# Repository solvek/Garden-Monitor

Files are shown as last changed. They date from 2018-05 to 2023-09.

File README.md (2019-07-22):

# Garden Monitor
A useful monitor for garden displaying information on dot-matrix
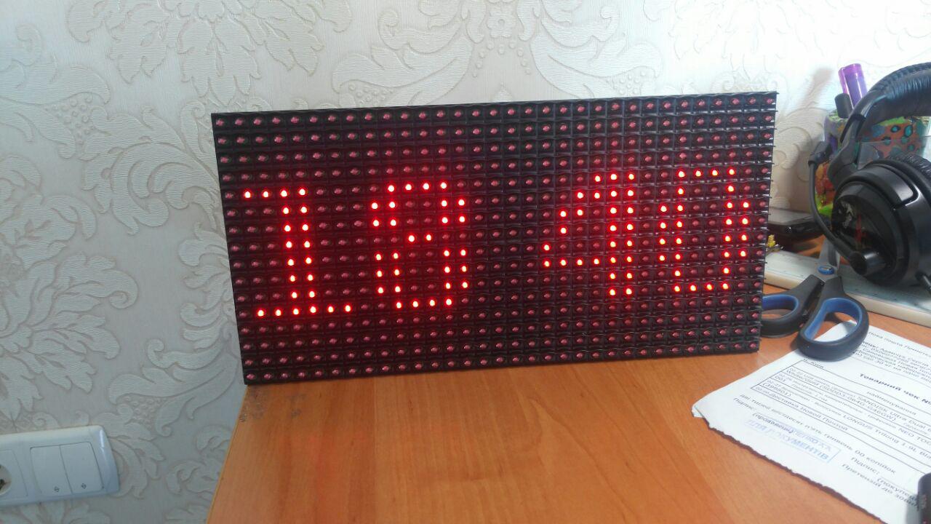
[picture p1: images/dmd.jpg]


# Terminal Commands

|Format|Description|Details|
|--|--|--|
|`#TYYMMDDDwHHmmSS`|Setting time|`#T19052405180500`.  `Dw` - day of week, Monday - `01`, Sunday - `07`|
|`#R`|Resets the device|
|`#BNNN`|Setting brightness|NNN - are 3 digits. Use 015 for 15. The value between 000 and 255|
|`#KSNNN`|Sends current temperature from sensor|NNN - are 3 digits. Use 015 for 15. S - sign "-" or "+"|
|`#CNNNMMM`|Sets temperature correction parameters|NNN and MMM - are bytes B and K. Example `#C128098`|

# Hardware

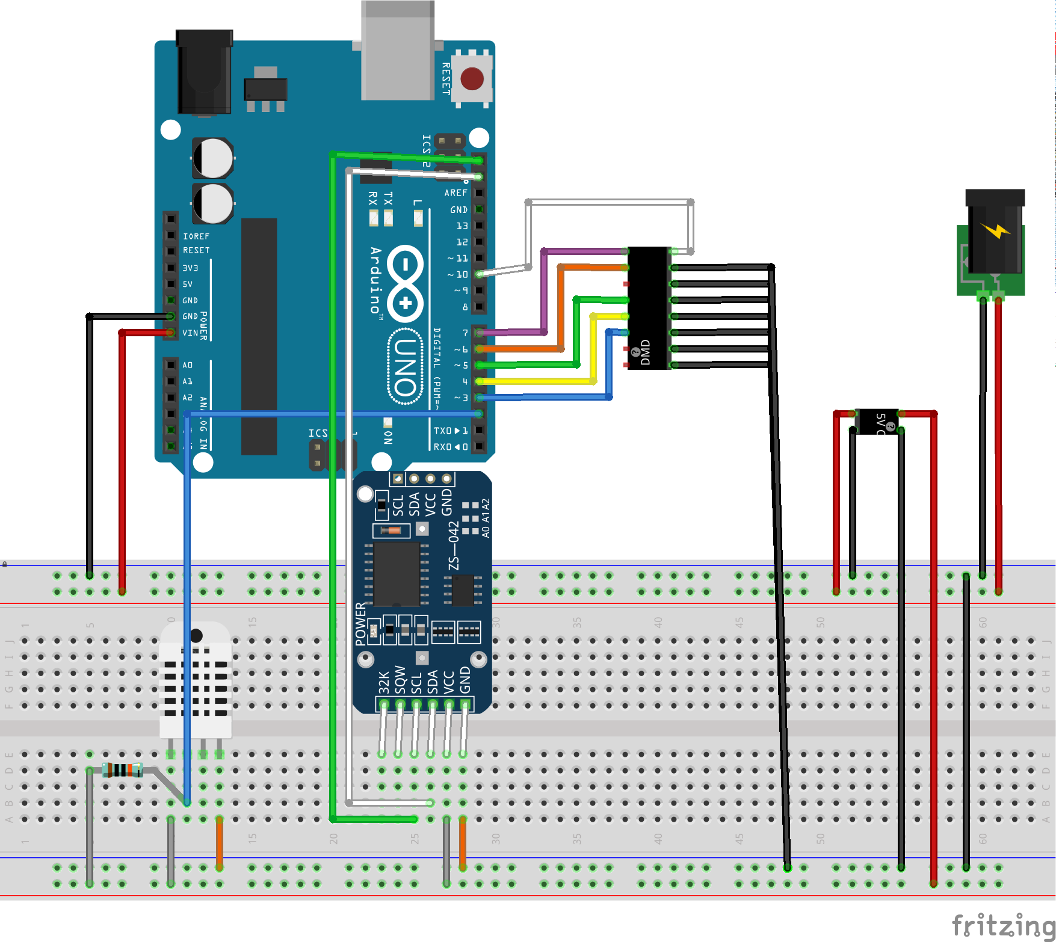
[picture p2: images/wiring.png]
Garden monitor wiring


I played with different controllers. P10 screen works with operating voltage 5V so only Anrduino Uno worked fine.

## [RTC](https://www.makeuseof.com/tag/how-and-why-to-add-a-real-time-clock-to-arduino/)

* [DS3231 Library](https://github.com/NorthernWidget/DS3231

## DHT22
Temperature and humidity sensor
* [DHT Library](https://github.com/adafruit/DHT-sensor-library)

## P10 Dot-Matrix display
 * [DMD2 Library](https://github.com/freetronics/DMD2)
 * [Instructable article](http://www.instructables.com/id/Display-Text-at-P10-LED-Display-Using-Arduino/)
 * [Linking dot matrix to Arduino](https://maker.pro/projects/arduino/arduino-led-matrix-controlled-android-app-greenpaks-i2c)
 *  [Font creator (Java based, use GLCDFontCreator2.zip)](https://code.google.com/archive/p/glcd-arduino/downloads)
	 * Running FontCreator:  `java -classpath . FontCreator`

### Wiring
Because BLE shield and DMD conflict for pins I used not standard DMD pins (`Arduino(Def)`) but custom (`Arduino(My)`)

|Letter|Meaning|Wire|Arduino(Def)|Arduino(My)|ESP8266|D1/R1|
|--|--|--|--|--|--|--|
|OE|NOE|White|D9|D10|GPIO15|D8|
|A|A|Purple|D6|D7|GPIO16|D2|
|B|B|Orange|D7|D6|GPIO12|D6|
|S|sck|Green|D13|D5|GPIO14|D5|
|L|clk|Yellow|D8|D4|GPIO0|D10|
|R|R|Blue|D11|D3|GPIO13|D7|

### Bus mapping

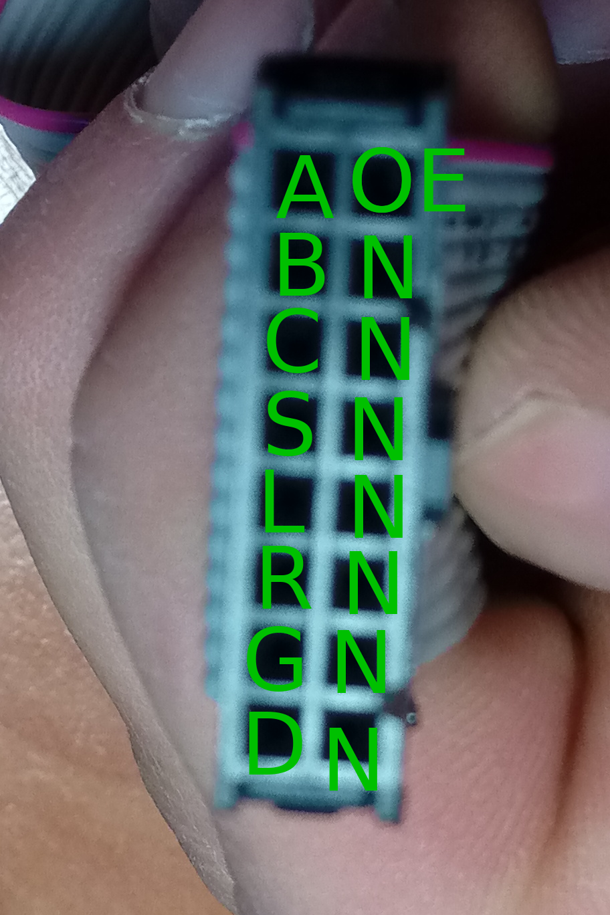
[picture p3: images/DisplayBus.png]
Bus mapping


[Connecting to ESP8266](http://forum.freetronics.com/viewtopic.php?t=6687)

## BLE Shield
 * [Library](https://github.com/RedBearLab/nRF8001)

## Other hardware
### [The 74HC595 Shift Register](https://learn.adafruit.com/adafruit-arduino-lesson-4-eight-leds/the-74hc595-shift-register)

### [Wemos D1/R1 Controller](https://wiki.wemos.cc/products:d1:d1)

 * [Mapping GPIOs to Ds](https://jardikblog.wordpress.com/2016/11/02/wemos-d1-r1-vs-wemos-d1-r2/)
 * [How to Program ESP8266 with Arduino UNO](https://www.hackster.io/harshmangukiya/how-to-program-esp8266-with-arduino-uno-efb05f)

|Arduino|D1/R1 label|GPIO|
|--|--|--|
|D2|TX1/D9|GPIO2|
|D6|D2|GPIO16|
|D7|D12/MISO/D6|GPIO12|
|D8|D10/SS|GPIO15|
|D9|D8|GPIO0|
|D11|D11/MOSI/D7|GPIO13|
|D13|D13/SCK/D5|GPIO14|
|A4|D14/SDA/D4|GPIO4|
|A5|D15/SCL/D3|GPIO5|

#### Libraries
##### [WiFiManager](https://github.com/tzapu/WiFiManager)
##### [NTPClient](https://github.com/arduino-libraries/NTPClient)
##### [ArduinoJson](https://github.com/bblanchon/ArduinoJson)
  
# Accuweather
* [Request for current weather condition](https://developer.accuweather.com/accuweather-current-conditions-api/apis/get/currentconditions/v1/%7BlocationKey%7D)
* Kyiv location key: 324505
# Others
 * [Online Markdown editor](https://stackedit.io)

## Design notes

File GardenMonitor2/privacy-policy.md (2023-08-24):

# Privacy Policy

Garden Monitor takes your privacy seriously. To better protect your privacy I provide this privacy policy notice explaining the way your personal information is collected and used.

## Collection of Routine Information

This app track basic information about their "users". This information includes, but is not limited to, IP addresses, "app" details, timestamps and referring pages. None of this information can personally identify specific "user" to this "app". The information is tracked for routine administration and maintenance purposes.

## Cookies

Where necessary, this "app" uses cookies to store information about a visitor’s preferences and history in order to better serve the "user" and/or present the "user" with customized content.

## Advertisement and Other Third Parties

Advertising partners and other third parties may use cookies, scripts and/or web beacons to track "user" activities on this "app" in order to display advertisements and other useful information. Such tracking is done directly by the third parties through their own servers and is subject to their own privacy policies. This "app" has no access or control over these cookies, scripts and/or web beacons that may be used by third parties. Learn how to [opt out of Google’s cookie usage](http://www.google.com/privacy_ads.html).

## Links to Third Party Websites

"I" have included links on this "app" for your use and reference. "I" are not responsible for the privacy policies on these websites. You should be aware that the privacy policies of these websites may differ from "my" own.

## Security

The security of your personal information is important to "us", but remember that no method of transmission over the Internet, or method of electronic storage, is 100% secure. While "I" strive to use commercially acceptable means to protect your personal information, "I" cannot guarantee its absolute security.

## Changes To This Privacy Policy

This Privacy Policy is effective as of 08/24/2023 and will remain in effect except with respect to any changes in its provisions in the future, which will be in effect immediately after being posted on this page.

"I" reserve the right to update or change "my" Privacy Policy at any time and you should check this Privacy Policy periodically. If "I" make any material changes to this Privacy Policy, "I" will notify you either through the email address you have provided "me", or by placing a prominent notice on "my" "app".

## Contact Information

For any questions or concerns regarding the privacy policy, please send "me" an email to sergi79@ukr.net.

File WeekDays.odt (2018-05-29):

П | ВТ | СР | ЧТ | ПТ | СБ | Н
П | ВТ | СР | ЧТ | ПТ | СБ | Н
П | ВТ | СР | ЧТ | ПТ | СБ | Н

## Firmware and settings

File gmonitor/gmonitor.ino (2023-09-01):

//"RBL_nRF8001.h/spi.h/boards.h" is needed in every new project
#include <SPI.h>
#include <EEPROM.h>
#include <boards.h>
#include <RBL_nRF8001.h>

#include <DMD2.h>
#include "fonts/GMSolvek.h"

#define panel_width 1
#define panel_heigh 1

#ifdef ESP8266
SPIDMD dmd(panel_width, panel_heigh, D3, D4, D6, D10);
#else
#define PIN_NOE 10 // White
#define PIN_A 7 // Purple
#define PIN_B 6 // Orange
#define PIN_SCK 5 // Green, Latch
#define PIN_CLK 4 // Yellow
#define PIN_R 3 // Blue, MOSI
SoftDMD dmd(panel_width,panel_heigh, PIN_NOE, PIN_A, PIN_B, PIN_SCK, PIN_CLK, PIN_R);
#endif

// Number of P10 panels used X, Y
DMD_TextBox box(dmd, 2, 1, 32, 16); 
//// Set Box (dmd, x, y, Height, Width)

#include <DHT.h>
#include <Wire.h>

#define DHTPIN 2     // what pin we're connected to
#define DHTTYPE DHT22   // DHT 22  (AM2302)
DHT dht(DHTPIN, DHTTYPE); //// Initialize DHT sensor for normal 16mhz Arduino

#include "DS3231.h"
RTClib RTC;
DS3231 Clock;

#define ADDR_BRIGHTNESS 116
#define ADDR_T_CORR 120

double correl_b, correl_k;

#include "Config.h"

#define STATE_TIME 1
#define STATE_TICK_ON 2
#define STATE_TICK_OFF 3
#define STATE_TICK_DATE 4
#define STATE_TICK_TEMP 5

byte state = 0;
long state_time;
long m, recentM = -100000;
byte tick;


void setup()
{  
  // Enable serial debug
  Serial.begin(57600);
  
  Serial.println(F("Started device"));

  dmd.setBrightness(EEPROM.read(ADDR_BRIGHTNESS));
  dmd.selectFont(GMSolvek); // Font used
  dmd.begin();     // Start DMD 
  Serial.println(F("Display initialized"));  
  
  // Default pins set to 9 and 8 for REQN and RDYN
  // Set your REQN and RDYN here before ble_begin() if you need
  // ble_set_pins(3, 2);
  
  // Set your BLE Shield name here, max. length 10
  ble_set_name("SolvekGM");
  
  // Init. and start BLE library.
  ble_begin();

  // DHT init
  dht.begin();
  Wire.begin();

  byte paramB = EEPROM.read(ADDR_T_CORR),
    paramD = EEPROM.read(ADDR_T_CORR+1);
  setCorrelation(paramB, paramD);
}

int c;

#define CHANNEL_SERIAL 1
#define CHANNEL_BLE 2
int channel = CHANNEL_SERIAL;

// Buffer for BLE
unsigned char buf[16] = {0};
unsigned char len = 0;

void loop()
{
  m = millis();
  if (m-recentM>state_time) nextState();
  
  if ( ble_available() )
  {
    while ( ble_available() ){
      c = ble_read();
      if (c==35){
        channel = CHANNEL_BLE;
        readCommand();
      }
      
      Serial.write(c);
    }
      
    Serial.println();
  }
  
  if ( Serial.available() )
  {
    delay(5);
    
    while ( Serial.available() ){
      c = Serial.read();
      if (c==35){
        channel = CHANNEL_SERIAL;
        readCommand();
      }
//      Serial.println(c);
      ble_write(c);
    }
  }
  
  ble_do_events();
}

void nextState(){
  recentM = m;
  transitState();
  state_time = 500;
  switch(state){
    case STATE_TIME:
      showTime();
      tick = 0;
      break;
    case STATE_TICK_ON:
      showTickOn();
      break;            
    case STATE_TICK_OFF:
      showTickOff();
      break;      
    case STATE_TICK_DATE:
      state_time = DELAY_DATE*1000;
      showDate();
      break;      
    case STATE_TICK_TEMP:
      state_time = DELAY_TEMP*1000;
      showTemp();
      break;      
  }
}

void transitState(){
  if (state == STATE_TICK_OFF && tick<DELAY_TIME){
    state = STATE_TICK_ON;
    tick++;
  }
  else {
    state++;
  }
  if (state > STATE_TICK_TEMP) state= STATE_TIME;
}

DateTime now;
inline void showTime(){
  now = RTC.now();
  dmd.clearScreen();
  dmd.drawString(1,3,padZero(now.hour()));
  dmd.drawString(18,3,padZero(now.minute()));
}

inline void showTickOn(){
  dmd.drawBox(15,5,16,6);
  dmd.drawBox(15,9,16,10);
}

inline void showTickOff(){
  dmd.drawBox(15,5,16,10, GRAPHICS_OFF);
}

int dow;
inline void showDate(){
  dmd.clearScreen();
  dmd.drawString(1,3,padZero(now.day())+F(".")+padZero(now.month()));    
  dow = Clock.getDoW();

//    Serial.print(F("Day of week from RTC: "));
//    Serial.println(dow);

    dow = 33*(dow-1)/7;

    dmd.drawLine(dow,0,dow+3,0);
    dmd.drawLine(dow,15,dow+3,15);    
//    Serial.println(now.year());
}

int hum, temp, tmp;
float st;
String t;

inline void showTemp(){
  hum = dht.readHumidity()*63/100;
  st = dht.readTemperature();

  if (st == st){
    temp = st*correl_k+correl_b;
    Serial.print(F("Sensor tmp: "));
    Serial.println(st);
    Serial.print(F("Corrd tmp: "));
    Serial.println(temp);
    ble_write('#');
    ble_write('K');
    if (st < 0){
      ble_write('-');
      st = - st;
    }
    else {
      ble_write('+');
    }
    t = padZero(st*10);
    ble_write(t.charAt(0));
    ble_write(t.charAt(1));
    ble_write(t.charAt(2));
    ble_write('\13');
  }else {
      Serial.println(F("Could not read temperature from sensor. Using previous value"));
  }

//  Serial.print(F("Sensor temperature: "));
//  Serial.println(temp);

  tmp = temp/*+tmpCorrection*/;
//    tmp = 44;
  dmd.clearScreen();
  t = String();
  if (tmp>0) t += String(F("+"));
  t +=String(tmp)+F("&");
  dmd.drawString(((tmp>-10) && (tmp<10)) ? 10 : 4,3,t);
  dmd.drawLine(0,0,hum-1,0);
  dmd.drawLine(0,15,hum-1,15);  
}

String padZero(int val){
  String s = String(val);
  if (val < 10) s = "0"+s;
  return s;
}

void(* commandRestart) (void) = 0;

void readCommand(){
  int r = inputSymbol();
  if (r == 84 || r == 116){ // T
    commandSetTime();
  }
  else if (r == 66 || r == 98){ // B
    commandSetBrightness();
  }
  else if (r == 82 || r == 114){ // R
    commandRestart();
  }  
  else if (r == 67 || r == 99){ // C
    commandCorrelation();
  }  
  else {
    Serial.print(F("Unknown command: "));
    Serial.println(r);
  }
}

void commandSetTime(){
//  Serial.println("Setting time");
  Clock.setYear(readNumeral(2));
  Clock.setMonth(readNumeral(2));
  Clock.setDate(readNumeral(2));
  Clock.setDoW(readNumeral(2));
  Clock.setHour(readNumeral(2));
  Clock.setMinute(readNumeral(2));
  Clock.setSecond(readNumeral(2));
}

void commandSetBrightness(){
  byte b = (byte)readNumeral(3);
  changeBrightness(b);
}

void commandCorrelation(){
  byte paramB = readNumeral(3),
    paramD = readNumeral(3);
  EEPROM.write(ADDR_T_CORR, paramB);
  EEPROM.write(ADDR_T_CORR+1, paramD);
  setCorrelation(paramB, paramD);
}

void changeBrightness(byte b){
  Serial.print(F("Setting brightness: "));
  Serial.println(b);
  dmd.end();
  dmd.begin();
  dmd.setBrightness(b);
  dmd.drawFilledBox(0,0,b/8,15);
  EEPROM.write(ADDR_BRIGHTNESS, b); 
}

int readNumeral(int count){
  int r = 0;
  for(int i=0;i<count;i++){
    r *= 10;
    r += inputSymbol()-48;
  }
  Serial.print(F("Got numeral:"));
  Serial.println(r);
  return r;
}

int inputSymbol(){
  int s;
  if (channel == CHANNEL_SERIAL) {
    while((s=Serial.read()) == -1);
  }
  else {
    while((s=ble_read()) == -1);
  }
  return s;
}

float M=50;
float G = -M/atanh(-128.0/129);

void setCorrelation(byte paramB, byte paramD){
  correl_b = unpack(paramB);
  correl_k = (20+unpack(paramD)-correl_b)/20.0;

  Serial.println(F("Correlation setup"));
  Serial.print(F("M: "));
  Serial.println(M);
  Serial.print(F("G: "));
  Serial.println(G);  
  Serial.print(F("Param B: "));
  Serial.println(paramB);
  Serial.print(F("Param D: "));
  Serial.println(paramD);
  Serial.print(F("Correl B: "));
  Serial.println(correl_b);
  Serial.print(F("Correl K: "));
  Serial.println(correl_k);
}

float atanh(float x){
  if (x < 0) return -atanh(-x);
  
  float r = x;
  float px = x;
  float d;
  for(int i=0;i<1000;i++){
    px = px*x*x;
    d = px/(2*i+3);
    r += d;
    if (d < 0.00001){
      break;
    }
  }

  return r;
}

float unpack(int p){
  return G*atanh((p-128)/129.0);
}

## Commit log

2018-04-24 Reading temperature, date and time
2018-04-26 Possibility to set datetime via spi
2018-05-11 1. Created wiring scheme 2. Added more details to README
    [gardmon.fzz]
2018-05-11 Improved temperature displaying
2018-05-11 Fixed setting time (day of week)
    [gmonitor.ino]
2018-05-14 Reverted dayweek displaying (reverted from commit b99fa5020b961e8bef965c3e637e92a4193ecfc9)
    [gmonitor.ino]
2018-05-14 Added DMD to wiring scheme
    [gardmon.fzz]
2018-05-15 Added general view image and wiring scheme
    [gardmon.fzz]
2018-05-29 1. Fixed link to wiring 2. Added weeks sheet
2018-07-02 Added info regarding WiFiManager
    [gardmon.fzz]
2018-09-20 Added config sample file
2018-09-20 Getting current weather condition from accuweather
2018-09-20 Correcting sensor temperature with the value received from accuwather
    [gmonitor.ino]
2018-09-21 Added commands for reseting wifi and device
    [gmonitor.ino]
2019-03-29 1. Added mapping of bus for DMD image 2. If sensor does not return temperature then prev value will be used
    [gardmon.fzz]
2019-03-29 Changed wiring to wemos controller
    [gardmon.fzz]
2019-03-29 Restarting device in 2 hours if wifi not established on start
2019-04-22 Modified wiring
    [gardmon.fzz]
2019-04-25 Migrating to Arduino Uno
2019-05-24 Arduino UNO with BLE shield
2019-05-24 Sending current temperature via BLE
2019-05-24 Sending sign with temperature
2019-05-24 Showing temperature on android
2019-05-28 Added temperature correction feature
    [gmonitor.ino]
2019-05-29 1. Updated wiring 2. Sending temperature data to firebase from android app
    [gardmon.fzz]
2023-08-22 Implemented time calibration
2023-08-22 Not starting calibration if it is already in progress
2023-08-22 Time calibration works now
2023-08-22 Reading sensor temperature from device
2023-08-22 Reading temperature from sensor and from accuweather
2023-08-22 Storing data in room db. Calibrating temperature.
2023-08-23 Hiding calibrate button while calibration is in progress
2023-08-23 Other method for getting sensor temperature
2023-08-23 Fixed UI problem with disabling button
2023-08-23 Calibrating params should be both unsigned values - used int instead of byte type
2023-08-24 Not calibrating temperature if params are not bytes. Handling errors while calculating params.
2023-08-24 Showing more details about the result of temperature calibration calc
2023-08-30 Calibrating temperature by only shifting value
2023-09-01 New approach for temperature calibration
2023-09-01 Implemented on android side new approach for calibrating temperature
2023-11-20 Calibrate time in parallel with temperature requesting
2023-11-20 Sometimes incoming temperature response can have invalid characters
